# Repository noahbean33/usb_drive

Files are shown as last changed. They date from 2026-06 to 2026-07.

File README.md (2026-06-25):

# Smart USB Thumb Drive — 64 GB, 4-Layer PCB (KiCad)

A fully routed, manufacture-ready 64 GB USB thumb drive PCB designed from scratch in KiCad. This project demonstrates high-speed digital design, BGA escape routing, impedance-controlled differential pairs, and multi-layer power distribution — all within the physical constraints of a standard USB stick form factor.

## What This Project Is

This is a complete hardware design for a "smart" USB thumb drive built around:

- **RP2040** — Dual-core Arm Cortex-M0+ microcontroller (Raspberry Pi silicon)
- **MTFC64GAPALBH-IT** — 64 GB eMMC NAND flash in a 153-ball TFBGA package (0.5 mm pitch)
- **USB2244** — USB 2.0 to eMMC bridge controller
- **SY8253ADC** — Synchronous buck converter for regulated power
- **LM66100** — Dual ideal-diode OR-ing circuit for power path management
- **INA226** — High-side/low-side current and power monitor (I2C)
- **SSD1306** — 0.91" 128×32 OLED display for status readout
- **TMP119** — Digital temperature sensor
- **TVS diode arrays** — ESD protection on both USB ports

The drive is not just storage — the RP2040 provides programmable logic for monitoring power draw, temperature, and storage status via the OLED, making it a platform for embedded USB experimentation.

## How It Works

### Architecture

The schematic is split into hierarchical sheets for modularity:

| Sheet | Function |
|---|---|
| `oring_power` | Dual ideal-diode OR-ing (VBUS vs. external supply) |
| `buck_converter_power` | 3.3 V regulated rail from the OR'd input |
| `usb_bridge` | USB2244 bridge + ESD protection |
| `emmc_storage` | 64 GB eMMC with full 8-bit data bus |
| `rp2040` | MCU core, crystal, SWD, boot circuitry |
| `sensors` | INA226 current monitor + TMP119 temperature sensor |
| `gpio` | RP2040 breakout headers for development |

### PCB Stackup (4 layers)

| Layer | Purpose |
|---|---|
| F.Cu | Signal routing (USB diff pairs, eMMC data bus) |
| In1.Cu | Solid ground plane |
| In2.Cu | Power distribution plane |
| B.Cu | Signal routing (secondary) |

The dedicated ground and power planes provide low-impedance return paths and controlled impedance for high-speed signals.

## Key Design Decisions

### 1. BGA Escape Routing (Via-in-Pad)

The 153-ball eMMC package at 0.5 mm pitch cannot be escaped with surface traces alone. I used **via-in-pad** with 0.3 mm diameter / 0.15 mm drill vias placed directly on BGA pads, transitioning signals to inner layers. Custom DRC rules relax annular width minimums (0.075 mm) and clearances specifically within the BGA courtyard to allow this dense routing while maintaining DRC coverage everywhere else.

### 2. Impedance-Controlled USB 2.0 Differential Pairs

USB D+/D− pairs are routed as impedance-controlled differential pairs targeting 90 Ω differential impedance. Trace geometry was calculated using a stack-up impedance tool and verified against the fabricator's capabilities. Tight coupling is maintained throughout the route.

### 3. eMMC Data Bus Length Matching

The 8-bit parallel eMMC data bus is length-matched to ±3 mm (data lines) and ±5 mm (clock), meeting timing requirements for HS400-class operation. KiCad's tuning patterns (meander routing) are applied with 80% corner radius to minimize reflections.

### 4. Dual Ideal-Diode Power OR-ing

Rather than a simple regulator off VBUS, the power architecture uses two TI LM66100 ideal diodes in an OR-ing configuration. This allows the board to be powered from either USB port seamlessly, with near-zero reverse current and minimal voltage drop — critical for a bus-powered device with tight power budgets.

### 5. Custom DRC Rules

Instead of globally weakening design rules to accommodate BGA and fine-pitch ICs, I wrote **per-component DRC exceptions** in KiCad's custom rules language. Each rule is scoped by courtyard (`insideCourtyard`) so that strict defaults (0.1 mm clearance, standard annular widths) apply everywhere except where the design explicitly requires tighter geometry.

### 6. Teardrops and Reliability Features

Teardrops are enabled on all vias, PTH pads, and SMD pads to improve mechanical robustness and reduce stress risers during thermal cycling — important for a device that will be repeatedly plugged and unplugged.

## Repository Structure

```
├── Smart USB Drive - Course.kicad_pro    # KiCad project file
├── Smart USB Drive - Course.kicad_sch    # Top-level schematic
├── Smart USB Drive - Course.kicad_pcb    # PCB layout
├── Smart USB Drive - Course.kicad_dru    # Custom design rules
├── oring_power.kicad_sch                 # Power OR-ing sub-sheet
├── buck_converter_power.kicad_sch        # Buck converter sub-sheet
├── usb_bridge.kicad_sch                  # USB bridge sub-sheet
├── emmc_storage.kicad_sch                # eMMC storage sub-sheet
├── rp2040.kicad_sch                      # RP2040 MCU sub-sheet
├── sensors.kicad_sch                     # Sensors sub-sheet
├── gpio.kicad_sch                        # GPIO breakout sub-sheet
├── Gerbers-Smart_USB_v1.1/               # Production-ready Gerber files
├── Datasheets/                           # Component datasheets
└── Library/                              # Custom symbols, footprints, 3D models
```

## Tools Used

- **KiCad 8** — Schematic capture, PCB layout, DRC, and Gerber generation
- **NextPCB HQDFM** — Design-for-manufacturing verification and impedance stack-up calculation

## Skills Demonstrated

- Multi-layer PCB design with impedance control
- BGA fanout and via-in-pad escape routing
- High-speed differential pair routing (USB 2.0)
- Parallel bus length matching with meander tuning
- Hierarchical schematic design for complex systems
- Power architecture design (ideal-diode OR-ing, buck regulation)
- Custom DRC rule authoring in KiCad
- Full manufacturing output generation (Gerbers, BOM, pick-and-place)

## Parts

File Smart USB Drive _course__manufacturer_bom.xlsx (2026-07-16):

Reference | Quantity | Value | Footprint | MPN | Manufacturer | Description | Distributor | Unit Price | Currency | Stock | Notes
U301 | 1 | SY8253ADC | Package_TO_SOT_SMD:TSOT-23-6 | SY8253ADC | Silergy |  | Karl Kruse GmbH | 0 | USD | 10000
R501,R502 | 2 | 27.4/1% | Resistor_SMD:R_01005_0402Metric | RC0402FR-0727R4L | YAGEO | RES 27.4 OHM 1% 1/16W 0402 | digikey |  | USD | 762370
U403,U502 | 2 | D3V3XA4B10LP | Package_DFN_QFN:Diodes_UDFN-10_1x2.5mm_P0.5mm | D3V3XA4B10LP7 | Diodes Incorporated | Dataline Protection PP U-DFN2510-10 T&R | RS UK | 0.0675 | USD | 2825
U702,U703 | 2 | INA226 | Package_SO:TSSOP-10_3x3mm_P0.5mm | INA226AIDGST | Texas Instruments |  | Ozdisan | 2.5958 | USD | 0
U402 | 1 | USB2244-AEZG-06 | footprints:QFN36_6X6MC_MCH | USB2244AEZG06TR | Microchip Technology | Ultra Fast USB 2.0 SD/MMC Flash Media Controller | Microchip Technology Inc | 2.51 | USD | 3000
J802 | 1 | Conn_01x03 | Connector_JST:JST_GH_SM03B-GHS-TB_1x03-1MP_P1.25mm_Horizontal | SM03BGHSTBLFSN | JST |  | Heilind Americas | 0.1721 | USD | 0
U501 | 1 | RP2040 | RP2040_minimal_r2:RP2040-QFN-56 | SC0914(13) | Raspberry Pi | IC MCU 32BIT EXT MEM 56QFN | digikey |  | USD | 114012
R405 | 1 | 330/1% | Resistor_SMD:R_01005_0402Metric | CRCW04023K30FKTD | Vishay Intertechnology | Thick Film Resistors - SMD 3.3k ohm 1% | TTI Americas | 0.0168 | USD | 10000
R506,R507 | 2 | 4.7K/1% | Resistor_SMD:R_01005_0402Metric | RC0402FR-074K7L | YAGEO | RES 4.7K OHM 1% 1/16W 0402 | digikey |  | USD | 2530392
R406 | 1 | 10K /1% | Resistor_SMD:R_01005_0402Metric | CRCW040210K0FKED | Vishay Intertechnology | Thick Film Resistors - SMD 10k ohm 1% | TTI Americas | 0.0013 | USD | 9120000
R504,R801,R802,R803 | 4 | 1k | Resistor_SMD:R_0402_1005Metric | 1K0402 | Not Specified |  | Cyclops Electronics | 0 | USD | 940
R403 | 1 | 12K /1% | Resistor_SMD:R_01005_0402Metric | CRCW040212K0FKED | Vishay Intertechnology | Thick Film Resistors - SMD 12k ohm 1% | TTI Americas |  | USD | 230000
C514 | 1 | 10u/10V | Capacitor_SMD:C_0805_2012Metric | CL21A106KPFNNNE | Samsung Electro-Mechanics | CAP CER 10UF 10V X5R 0805 | digikey |  | USD | 93830
R303,R503 | 2 | 1K/1% | Resistor_SMD:R_01005_0402Metric | CRCW040251K1FKED | Vishay Intertechnology | Thick Film Resistors - SMD 51.1k ohm 1% | TTI Americas | 0.0018 | USD | 530000
U401 | 1 | AT24CS04-STUM | Package_TO_SOT_SMD:SOT-23-5 | AT24CS04STUMT | Microchip Technology | EEPROM - Serial-I²C - 4Kbit (512 x 8) - 1.8V/2.5V/3.3V/5V - 5-Pin SOT-23 - Tape&Reel | Master Electronics | 0.2921 | USD | 20000
U201,U202 | 2 | LM66100DCK | Package_TO_SOT_SMD:SOT-363_SC-70-6 | LM66100DCKR | Texas Instruments | IC OR CTRLR IDEAL DIODE SC70-6 | digikey |  | USD | 13643
R610 | 1 | 22/1% | Resistor_SMD:R_01005_0402Metric | 22104028 | Molex | KK 100 HDR FLAT VERT 30 AU 2CKT | RS Americas | 0.477 | USD | 0
R401,R402,R404,R609,R612 | 5 | 10K/1% | Resistor_SMD:R_01005_0402Metric | TNPW040210K1BEED | Vishay Intertechnology | Thin Film Resistors - SMD 10.1k ohm .1% 25ppm 1/10w | TTI Americas |  | USD | 0
R302 | 1 | 22.1K/1% | Resistor_SMD:R_01005_0402Metric | RC0402FR-0722K1L | YAGEO | RES 22.1K OHM 1% 1/16W 0402 | digikey |  | USD | 407819
R202,R204 | 2 | 150K/1% | Resistor_SMD:R_01005_0402Metric | CRG0402J150K10 | TE Connectivity | Thick Film Resistors - SMD crg0402 5% 150k | TTI Americas |  | USD | 0
Y401 | 1 | SG-210STF | Oscillator:Oscillator_SMD_SeikoEpson_SG210-4Pin_2.5x2.0mm | SG210SCB16000000MHzBQ33210B70000412 | Seiko Coporation |  | CoreStaff | 0.953 | USD | 2
R201,R203,R205,R301 | 4 | 100K/1% | Resistor_SMD:R_01005_0402Metric | M3253502E1B100KZMB | KEMET |  | TTI Americas |  | USD | 0
R107,R108 | 2 | 2m/1% | Resistor_SMD:R_Shunt_Ohmite_LVK12 | LVK12R010DER | Ohmite | Rohs Res., 0.01 Ohm, 1/2W, 0.5%, 1206 | Sensible Micro | 0 | USD | 466
R601,R602,R603,R604,R605,R606,R607,R608 | 8 | 47K/1% | Resistor_SMD:R_01005_0402Metric | RC0402FR-0747KL | YAGEO | RES 47K OHM 1% 1/16W 0402 | digikey |  | USD | 1409431
J801 | 1 | Conn_01x06 | Connector_JST:JST_SHL_SM06B-SHLS-TF_1x06-1MP_P1.00mm_Horizontal | SM06BSHLSTFLFSN | JST | CUT TAPE - 6-POS SHL CONN 1.0MM PITCH WtoB CRIMP ST | Interstate Connecting Components | 0.6487 | USD | 1194
L301 | 1 | 2.2uH/4,3A | Inductor_SMD:L_Sunlord_SWPA4020S | SWPA4020S4R7MT | sunlord |  | Kepictronics | 0 | USD | 2740
R103,R104,R105,R106 | 4 | 5.5K /1% | Resistor_SMD:R_01005_0402Metric | CRCW040225K5FKED | Vishay Intertechnology | Thick Film Resistors - SMD 25.5k ohm 1% | TTI Americas | 0.002 | USD | 0
C503,C504,C506,C508,C509,C510,C511,C512,C513,C515 | 10 | 1n / 10V | Capacitor_SMD:C_0402_1005Metric | C0402C102K8RACTU | KEMET | Multilayer Ceramic Capacitors MLCC - SMD/SMT 1000pf 10v 10% 0402 | TTI Americas | 0.0035 | USD | 300000
R101,R102 | 2 | 1M/1% | Resistor_SMD:R_01005_0402Metric | CRCW04021M10FKED | Vishay Intertechnology | Thick Film Resistors - SMD 1.1m ohm 1% | TTI Americas | 0.0018 | USD | 720000
C409 | 1 | 4.7u 10V | Capacitor_SMD:C_0603_1608Metric | C0603C475K8PAC7867 | KEMET | Multilayer Ceramic Capacitors MLCC - SMD/SMT 4.7uf 10v 10% 0603 | TTI Americas | 0.04 | USD | 244000
U601 | 1 | MTFC64GAPALBH-IT | footprints:BGA153N50P14X14_1300X1150X110N | MTFC64GAPALBHIT | Micron Technology | Emmc512G, Tray Rohs Compliant: Yes |Micron Technology MTFC64GAPALBH-IT | Newark | 0 | USD | 0
C603,C604,C605,C606,C607,C613 | 6 | 2.2u 10V | Capacitor_SMD:C_0402_1005Metric | C0402C225M8PACTU | KEMET | Multilayer Ceramic Capacitors MLCC - SMD/SMT 2.2uf 10v 20% 0402 | TTI Americas | 0.047 | USD | 950000
D302 | 1 | LED RED | LED_SMD:LED_0603_1608Metric | Q62702P5187 | ams OSRAM | Single Color LEDs s red smd led chip led 0603 | TTI Americas | 0.0223 | USD | 4000
C501,C502 | 2 | 15p 10V | Capacitor_SMD:C_0402_1005Metric | C0402C150J8GACTU | KEMET | Multilayer Ceramic Capacitors MLCC - SMD/SMT 15pf 10v 5% 0402 | TTI Americas |  | USD | 0
C401 | 1 | 100n 10V | Capacitor_SMD:C_0402_1005Metric | C0402C104K8RAC7867 | KEMET | Multilayer Ceramic Capacitors MLCC - SMD/SMT .1uf 10v 10% 0402 | TTI Americas | 0.0055 | USD | 5290000
C505,C507 | 2 | 1u /10V | Capacitor_SMD:C_0402_1005Metric | C0402C105K8PACTU | KEMET | Multilayer Ceramic Capacitors MLCC - SMD/SMT 1.0uf 10v 10% 0402 | TTI Americas | 0.0161 | USD | 510000
C302,C304,C305 | 3 | 22u 10V | Capacitor_SMD:C_0805_2012Metric | C0805C226M8PACTU | KEMET | Multilayer Ceramic Capacitors MLCC - SMD/SMT 22uf 10v 20% 0805 | TTI Americas | 0.1 | USD | 75000
C101,C102 | 2 | 2.2n 100V | Capacitor_SMD:C_0603_1608Metric | C0603C222K1RACTU | KEMET | Multilayer Ceramic Capacitors MLCC - SMD/SMT 2200pf 100v 10% 0603 | TTI Americas |  | USD | 96000
C201,C303,C403,C404,C602,C612 | 6 | 1u 10V | Capacitor_SMD:C_0402_1005Metric | C0402C105K8PACTU | KEMET | Multilayer Ceramic Capacitors MLCC - SMD/SMT 1.0uf 10v 10% 0402 | TTI Americas | 0.0161 | USD | 510000
C301,C402,C405,C406,C407,C408,C601,C608,C609,C610,C611 | 11 | 0.1u 10V | Capacitor_SMD:C_0402_1005Metric | C0402C104K8RAC7867 | KEMET | Multilayer Ceramic Capacitors MLCC - SMD/SMT .1uf 10v 10% 0402 | TTI Americas | 0.0055 | USD | 5290000
U503 | 1 | W25Q128JVS | Package_SO:SOIC-8_5.3x5.3mm_P1.27mm | W25Q128JVSIMTR | Winbond Electronics Corporation |  | EPI Tech | 4.375 | USD | 3505
U701 | 1 | TMP119AIYBGR | Package_BGA:Texas_DSBGA-6_0.95x1.488mm_Layout2x3_P0.4mm | TMP119AIYBGR | Texas Instruments |  | AERI | 4.055 | USD | 8308
J101,J102 | 2 | USB_C_Receptacle_USB2.0_16P | Connector_USB:USB_C_Receptacle_XKB_U262-16XN-4BVC11 | 2171790003 | Molex | USB CONN, R/A, TYPE C 2.0, RCPT, 16P; | element14 Singapore | 0.8016 | USD | 624
D401,D801,D802,D803 | 4 | LED | LED_SMD:LED_0603_1608Metric | APTD1608LSURCK | Kingbright |  | AERI | 0.086 | USD | 27003
D301 | 1 | SMF5V0A | Diode_SMD:D_SMF | SMF5V0AHE3A08 | Vishay Intertechnology |  | EBV Elektronik | 0 | USD | 0
C701,C702 | 2 | 1u/10V | Capacitor_SMD:C_0402_1005Metric | CC0402KRX5R6BB105 | Yageo Corporation | Ceramic Capacitor, 1Uf, 10V, X5R, 10%, 0402; Capacitance:1Μf; Voltage(Dc):10V; Capacitor Case/Package:0402 [1005 Metric]; Capacitance Tolerance:± 10%; Dielectric Characteristic:X5R; Product Range:Cc Series; Product Length:1.02Mm Rohs Compliant: Yes |Yageo CC0402KRX5R6BB105 | Newark | 0.155 | USD | 3231033
Y501 | 1 | Crystal_GND24 | Crystal:Crystal_SMD_3225-4Pin_3.2x2.5mm | ABM812000MHZ12B1UT | Abracon |  | Ozdisan | 0.3695 | USD | 0
DS701 | 1 | OLED_SSD1306_0p91_128x32_I2C | footprints:SSD1306-0.91-OLED-4pin-128x32 |  |  |  |  |  | USD |  | Please leave unpopulated.
R505 | 1 | DNF | Resistor_SMD:R_0402_1005Metric |  |  |  |  |  | USD |  | Please leave unpopulated.
J501 | 1 | Conn_01x02 | Connector_PinHeader_2.54mm:PinHeader_1x02_P2.54mm_Vertical |  |  |  |  |  | USD |  | Please leave unpopulated.
TP204 | 1 | TestPoint | TestPoint:TestPoint_Pad_D1.5mm |  |  |  |  |  | USD |  | This is a testpoint, no part needed.
TP101,TP102,TP302,TP601 | 4 | TestPoint | TestPoint:TestPoint_Pad_D1.5mm |  |  |  |  |  | USD |  | This is a testpoint, no part needed.

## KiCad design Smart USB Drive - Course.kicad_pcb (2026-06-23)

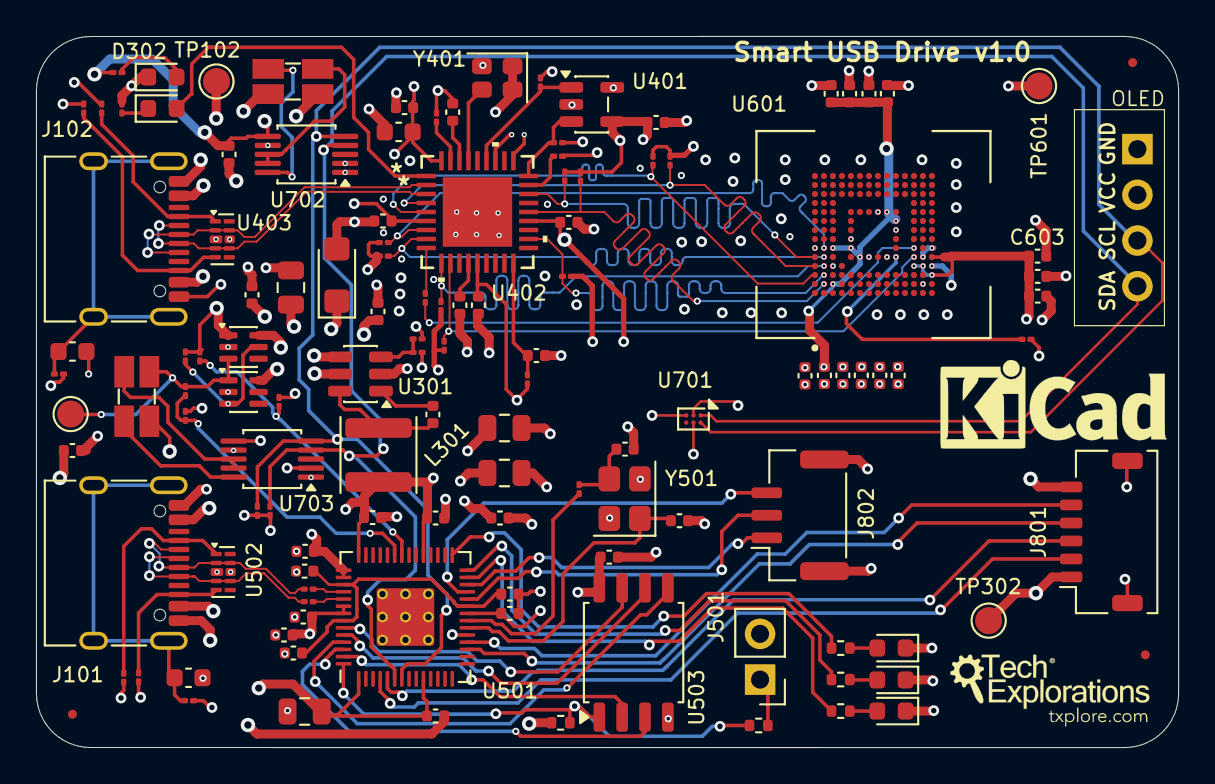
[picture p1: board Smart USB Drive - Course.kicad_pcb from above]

Board: 4 copper layers, 63.5 x 39.5 mm, 122 parts (0 on the bottom side), 77 nets.

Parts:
C101, C102: 2.2n 100V; C_0603_1608Metric
C201, C303, C403, C404, C602, C612: 1u 10V; C_0402_1005Metric
C301, C402, C405, C406, C407, C408, C601, C608, C609, C610, C611: 0.1u 10V; C_0402_1005Metric
C302, C304, C305: 22u 10V; C_0805_2012Metric
C401: 100n 10V; C_0402_1005Metric
C409: 4.7u 10V; C_0603_1608Metric
C501, C502: 15p 10V; C_0402_1005Metric
C503, C504, C506, C508, C509, C510, C511, C512, C513, C515: 1n / 10V; C_0402_1005Metric
C505, C507: 1u /10V; C_0402_1005Metric
C514: 10u/10V; C_0805_2012Metric
C603, C604, C605, C606, C607, C613: 2.2u 10V; C_0402_1005Metric
C701, C702: 1u/10V; C_0402_1005Metric
D301: SMF5V0A; D_SMF
D302: LED RED; LED_0603_1608Metric
D401, D801, D802, D803: LED; LED_0603_1608Metric
DS701: OLED_SSD1306_0p91_128x32_I2C; SSD1306-0.91-OLED-4pin-128x32
J101, J102: USB_C_Receptacle_USB2.0_16P; USB_C_Receptacle_XKB_U262-16XN-4BVC11
J501: Conn_01x02; PinHeader_1x02_P2.54mm_Vertical
J801: Conn_01x06; JST_SHL_SM06B-SHLS-TF_1x06-1MP_P1.00mm_Horizontal
J802: Conn_01x03; JST_GH_SM03B-GHS-TB_1x03-1MP_P1.25mm_Horizontal
L301: 2.2uH/4,3A; L_Sunlord_SWPA4020S
R101, R102: 1M/1%; R_01005_0402Metric
R103, R104, R105, R106: 5.5K /1%; R_01005_0402Metric
R107, R108: 2m/1%; R_Shunt_Ohmite_LVK12
R201, R203, R205, R301: 100K/1%; R_01005_0402Metric
R202, R204: 150K/1%; R_01005_0402Metric
R302: 22.1K/1%; R_01005_0402Metric
R303, R503: 1K/1%; R_01005_0402Metric
R401, R402, R404, R609, R612: 10K/1%; R_01005_0402Metric
R403: 12K /1%; R_01005_0402Metric
R405: 330/1%; R_01005_0402Metric
R406: 10K /1%; R_01005_0402Metric
R501, R502: 27.4/1%; R_01005_0402Metric
R504, R801, R802, R803: 1k; R_0402_1005Metric
R505: DNF; R_0402_1005Metric
R506, R507: 4.7K/1%; R_01005_0402Metric
R601, R602, R603, R604, R605, R606, R607, R608: 47K/1%; R_01005_0402Metric
R610: 22/1%; R_01005_0402Metric
TP101, TP102, TP302, TP601: TestPoint; TestPoint_Pad_D1.5mm
U201, U202: LM66100DCK; SOT-363_SC-70-6
U301: SY8253ADC; TSOT-23-6
U401: AT24CS04-STUM; SOT-23-5
U402: USB2244-AEZG-06; QFN36_6X6MC_MCH
U403, U502: D3V3XA4B10LP; Diodes_UDFN-10_1x2.5mm_P0.5mm
U501: RP2040; RP2040-QFN-56
U503: W25Q128JVS; SOIC-8_5.3x5.3mm_P1.27mm
U601: MTFC64GAPALBH-IT; BGA153N50P14X14_1300X1150X110N
U701: TMP119AIYBGR; Texas_DSBGA-6_0.95x1.488mm_Layout2x3_P0.4mm
U702, U703: INA226; TSSOP-10_3x3mm_P0.5mm
Y401: SG-210STF; Oscillator_SMD_SeikoEpson_SG210-4Pin_2.5x2.0mm
Y501: Crystal_GND24; Crystal_SMD_3225-4Pin_3.2x2.5mm

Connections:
+1V1: C503.1, C504.1, C505.1, U501.23 (DVDD), U501.45 (VREG_VOUT), U501.50 (DVDD)
/ORING_POWER/NOTIFY_3V3_CON1: R201.2, R202.1, U501.36 (GPIO24)
/ORING_POWER/NOTIFY_3V3_CON2: R203.2, R204.1, U501.37 (GPIO25)
/ORING_POWER/ORING_5V: C201.1, C301.1, C302.1, D301.1 (A1), U201.6 (VOUT), U202.6 (VOUT), U301.4 (EN), U301.5 (VIN)
/RP2040/GPIO14: J801.4, U501.17 (GPIO14)
/RP2040/GPIO15: J801.5, U501.18 (GPIO15)
/RP2040/I2C0_SCL: DS701.3 (SCL), R507.1, U501.7 (GPIO5), U701.A2 (SCL), U702.5 (SCL), U703.5 (SCL)
/RP2040/I2C0_SDA: DS701.4 (SDA), R506.1, U501.6 (GPIO4), U701.A1 (SDA), U702.4 (SDA), U703.4 (SDA)
/RP2040/I2C_SCL: J801.3, U501.5 (GPIO3)
/RP2040/I2C_SDA: J801.2, U501.4 (GPIO2)
/RP2040/LED_A: R801.2, U501.27 (GPIO16)
/RP2040/LED_B: R802.2, U501.28 (GPIO17)
/RP2040/LED_C: R803.2, U501.29 (GPIO18)
/RP2040/QSPI_SCLK: U501.52 (QSPI_SCLK), U503.6 (CLK)
/RP2040/QSPI_SD0: U501.53 (QSPI_SD0), U503.5 (DI/IO_{0})
/RP2040/QSPI_SD1: U501.55 (QSPI_SD1), U503.2 (DO/IO_{1})
/RP2040/QSPI_SD2: U501.54 (QSPI_SD2), U503.3 (~WP/IO_{2})
/RP2040/QSPI_SD3: U501.51 (QSPI_SD3), U503.7 (~HOLD/~RESET/IO_{3})
/RP2040/QSPI_SS: R504.1, R505.2, U501.56 (QSPI_SS), U503.1 (~CS)
/RP2040/RP_USB_D+: J101.A6 (D+), J101.B6 (D+), R501.2, U502.4, U502.7 (NC)
/RP2040/RP_USB_D-: J101.A7 (D-), J101.B7 (D-), R502.2, U502.2
/RP2040/RP_XIN: C501.1, U501.20 (XIN), Y501.1
/RP2040/RP_XOUT: R503.2, U501.21 (XOUT)
/RP2040/RUN: J802.1, U501.26 (RUN)
/RP2040/SWCLK: J802.2, U501.24 (SWCLK)
/RP2040/SWD: J802.3, U501.25 (SWD)
/RP2040/~USB_BOOT: J501.1, R504.2
/USB_BRIDGE/MMCD0: R601.2, U402.5 (SD_D0), U601.A3 (DAT0)
/USB_BRIDGE/MMCD1: R602.2, U402.4 (SD_D1), U601.A4 (DAT1)
/USB_BRIDGE/MMCD2: R603.2, U402.25 (SD_D2), U601.A5 (DAT2)
/USB_BRIDGE/MMCD3: R604.2, U402.23 (SD_D3), U601.B2 (DAT3)
/USB_BRIDGE/MMCD4: R605.2, U402.20 (SD_D4), U601.B3 (DAT4)
/USB_BRIDGE/MMCD5: R606.2, U402.10 (SD_D5), U601.B4 (DAT5)
/USB_BRIDGE/MMCD6: R607.2, U402.8 (SD_D6), U601.B5 (DAT6)
/USB_BRIDGE/MMCD7: R608.2, U402.7 (SD_D7), U601.B6 (DAT7)
/USB_BRIDGE/MMC_CLK: R610.2, U402.9 (SD_CLK)
/USB_BRIDGE/SCL_USB2244: R404.2, U401.1 (SCL), U402.31 (TXD/SCK)
/USB_BRIDGE/SDA_USB2244: R402.2, U401.3 (SDA), U402.27 (RXD/SDA)
/USB_BRIDGE/STORAGE_USB+: J102.A6 (D+), J102.B6 (D+), U402.2 (USB+), U403.2, U403.9 (NC)
/USB_BRIDGE/STORAGE_USB-: J102.A7 (D-), J102.B7 (D-), U402.3 (USB-), U403.4, U403.7 (NC)
/USB_CC1_CON1: J102.A5 (CC1), R105.2, U403.1
/USB_CC1_CON2: J101.A5 (CC1), R103.2, U502.1
/USB_CC2_CON1: J102.B5 (CC2), R106.1, U403.5
/USB_CC2_CON2: J101.B5 (CC2), R104.1, U502.5
/VBUS_MCU: R107.4, R203.1, TP101.1 (1_1), U201.3 (~CE), U202.1 (VIN)
/VBUS_MCU_IN+: R107.2, U703.10 (Vin+)
/VBUS_MCU_IN-: R107.3, U703.8 (Vbus), U703.9 (Vin-)
/VBUS_STORAGE: R108.4, R201.1, R205.1, TP102.1 (1_1), U201.1 (VIN)
/VBUS_STORAGE_IN+: R108.2, U702.10 (Vin+)
/VBUS_STORAGE_IN-: R108.3, U702.8 (Vbus), U702.9 (Vin-)
/eMMC_STORAGE/MMC_CLK_L: R610.1, U601.M6 (CLK)
/eMMC_STORAGE/MMC_CMD_L: R612.2, U402.11 (SD_CMD), U601.M5 (CMD)
GND: C101.2, C102.2, C201.2, C301.2, C302.2, C304.1, C304.2, C305.1, C305.2, C401.1, C401.2, C402.2, C403.1, C404.1, C405.1, C405.2, C406.1, C406.2, C407.1, C407.2, C408.1, C408.2, C409.1, C409.2, C501.2, C502.2, C503.2, C504.2, C505.2, C506.1, C506.2, C507.1, C507.2, C508.1, C508.2, C509.1, C509.2, C510.1, C510.2, C511.1, C511.2, C512.1, C512.2, C513.1, C513.2, C514.1, C514.2, C515.1, C515.2, C601.1, C601.2, C602.1, C602.2, C603.1, C603.2, C604.1, C604.2, C605.1, C605.2, C606.1, C606.2, C607.1, C607.2, C608.1, C608.2, C609.1, C609.2, C610.1, C610.2, C611.1, C611.2, C612.1, C612.2, C613.1, C613.2, C701.1, C701.2, C702.1, C702.2, D301.2 (A2), D302.1 (K), D801.1 (K), D802.1 (K), D803.1 (K), DS701.1 (GND), J101.A1 (GND), J101.A12 (GND), J101.B1 (GND), J101.B12 (GND), J102.A1 (GND), J102.A12 (GND), J102.B1 (GND), J102.B12 (GND), J501.2, J801.1, J801.6, J801.7 (MP1), J801.8 (MP2), J802.MP, L301.2, R101.2, R102.2, R103.1, R104.2, R105.1, R106.2, R202.2, R204.2, R301.1, R302.2, R303.1, R401.1, R402.1, R403.2, R404.1, R405.1, R406.1, R505.1, R506.2, R507.2, R601.1, R602.1, R603.1, R604.1, R605.1, R606.1, R607.1, R608.1, R609.2, R612.1, TP302.1 (1_1), TP601.1 (1_1), U201.2 (GND), U202.2 (GND), U301.2 (GND), U401.2 (GND), U401.4 (VCC), U401.5 (WP), U402.6 (VDD33), U402.14 (VDD33), U402.22 (VDD33), U402.28 (TEST), U402.30 (SD_WP), U402.36 (VDDA33), U402.37 (EPAD), U403.3 (VSS), U403.8 (VSS), U501.1 (IOVDD), U501.10 (IOVDD), U501.19 (TESTEN), U501.22 (IOVDD), U501.33 (IOVDD), U501.42 (IOVDD), U501.43 (ADC_AVDD), U501.44 (VREG_IN), U501.48 (USB_VDD), U501.49 (IOVDD), U501.57 (GND), U502.3 (VSS), U502.8 (VSS), U503.4 (GND), U503.8 (VCC), U601.A6 (VSS), U601.C2 (VDDIM), U601.C4 (VSSQ), U601.C6 (VCCQ), U601.E6 (VCC), U601.E7 (VSS__1), U601.F5 (VCC__1), U601.G5 (VSS__2), U601.H10 (VSS__3), U601.J5 (VSS__4), U601.J10 (VCC__2), U601.K8 (VSS__5), U601.K9 (VCC__3), U601.M4 (VCCQ__1), U601.N2 (VSSQ__1), U601.N4 (VCCQ__2), U601.N5 (VSSQ__2), U601.P3 (VCCQ__3), U601.P4 (VSSQ__3), U601.P5 (VCCQ__4), U601.P6 (VSSQ__4), U701.B1 (V+), U701.B2 (GND), U701.C1 (ADD0), U702.1 (A1), U702.2 (A0), U702.6 (VS), U702.7 (GND), U703.1 (A1), U703.2 (A0), U703.6 (VS), U703.7 (GND), Y401.1 (~ST), Y401.2 (GND), Y401.4 (Vcc), Y501.2 (G), Y501.4 (G)
unnamed: C502.1, R503.1, Y501.3
unnamed: D302.2 (A), R303.2
unnamed: D401.2 (A), U402.1 (LED)
unnamed: D401.1 (K), R405.2
unnamed: D801.2 (A), R801.1
unnamed: D802.2 (A), R802.1
unnamed: D803.2 (A), R803.1
unnamed: C101.1, J101.SH (SHIELD), R101.1
unnamed: J101.A4 (VBUS), J101.A9 (VBUS), J101.B4 (VBUS), J101.B9 (VBUS), R107.1
unnamed: C102.1, J102.SH (SHIELD), R102.1
unnamed: J102.A4 (VBUS), J102.A9 (VBUS), J102.B4 (VBUS), J102.B9 (VBUS), R108.1
unnamed: R205.2, U201.5 (ST), U202.3 (~CE)
unnamed: C303.1, U301.1 (BOOST)
unnamed: R301.2, R302.1, U301.3 (FB)
unnamed: C303.2, L301.1, U301.6 (SW)
unnamed: R403.1, U402.35 (RBIAS)
unnamed: C402.1, R401.2, U402.18 (RESET_N)
unnamed: R406.2, U402.26 (SD_NCD)
unnamed: U402.33 (XTAL1(CLKIN)), Y401.3 (OUT)
unnamed: C403.2, U402.13 (VDD18)
unnamed: C404.2, U402.34 (VDD18PLL)
unnamed: R502.1, U501.46 (USB_DM)
unnamed: R501.1, U501.47 (USB_DP)
unnamed: R609.1, U601.K5 (RST_N)

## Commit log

2026-05-28 initialized schematic
    [usb_drive_pcb.kicad_pcb, usb_drive_pcb.kicad_sch]
2026-06-23 implemented project
    [Smart USB Drive - Course-B_Cu - SIGNAL.gbl, Smart USB Drive - Course-B_Mask.gbs, Smart USB Drive - Course-B_Paste.gbp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]
2026-07-16 Add manufacturer BOM for Smart USB Drive
    Add Bill of Materials spreadsheet containing component specifications and quantities for manufacturing the Smart USB Drive project.
    [Smart USB Drive _course__manufacturer_bom.xlsx]
